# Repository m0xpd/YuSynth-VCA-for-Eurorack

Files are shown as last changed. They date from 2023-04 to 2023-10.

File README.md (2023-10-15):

# YuSynth-VCA-for-Eurorack

**A Eurorack Version of Yves Usson's 'Simple VCA'**



This repository contains design files for my Eurorack version of Yves Usson's 'Simple VCA' circuit:
http://yusynth.net/Modular/EN/VCA/index.html

which has been described in a stripboard implemementation on Eddy Bergman's Synth DIY site:
https://www.eddybergman.com/2020/04/synthesizer-build-part-29-vca-yusynth_25.html

**Circuit Description**

This Eurorack version is implemented on a single PCB, following closely Yves' original schematic.<p>(You can see my schematic as a graphic [here](https://github.com/m0xpd/YuSynth-VCA-for-Eurorack/blob/main/PCB/YuSynth%20Eurorack%20VCA%20Schematic.png) and the BoM is [here](https://github.com/m0xpd/YuSynth-VCA-for-Eurorack/blob/main/PCB/YuSynth%20VCA%20Eurorack%20v1%20BOM.txt) )

I have replaced the specified BC547 transistors with 2n3904s, as these are my everyday 'popcorn' NPNs. Yves does note this as a standard replacement 
and warns that the pinouts of the two transistors is revesed; 'CBE' becomes 'EBC'. 

My PCB is designed and silkscreened for 2n3904s, so if you want to swap back to the original BC547Cs, you'll have to place these 'in reverse' 
(i.e. with the flat face of the case aligned with the curve on the silkscreen).

I have also swapped the two IC packages (a TL072 and a LM741/TL071) for a single TL074 for two reasons:
Firstly, it is more efficient in terms of PCB area to do this.
Secondly, it is cheaper to do this; TL074s are more efficient than their smaller siblings (they only need one pair of power supply pins) but they're 
also very widely used so they are cheap, whereas TL072s and (particularly) TL071s are disproportionately expensive. Even more perversely, the old LM 
or uA741 (which was once the only op-amp in the shop) is now available only as a nostalgia piece, so it too sells for crazy money!

Having done this, I couldn't bear to have that extra op-amp stage doing nothing, so I gave both outputs independent active drive.

**Licensing the IP**

[][cc-by-nc-sa]

[cc-by-nc-sa]: http://creativecommons.org/licenses/by-nc-sa/4.0/
[cc-by-nc-sa-image]: https://licensebuttons.net/l/by-nc-sa/4.0/88x31.png
[cc-by-nc-sa-shield]: https://img.shields.io/badge/License-CC%20BY--NC--SA%204.0-lightgrey.svg  
  
Yves is clear on the position with copyright on his website:

"All circuits, schematics, printed circuit board, panel design and associated data published on (yusynth.net) can be used for private use only." 

and:

"The projects of (yusynth.net) may be build for personal, private usage or educative purpose. Commercial exploitation of the schematics, circuits, 
front panels and software shown on (yusynth.net), is not permitted without a formal agreement with (Yves Usson)".

Accordingly, **the copyright for this VCA circuit rests with Yves and no commercial exploitation is permitted**.

I have reflected this in the [License](LICENSE.txt) for the Eurorack version presented in this repository.

This work is licensed under a
[Creative Commons Attribution-NonCommercial-ShareAlike 4.0 International License.](https://creativecommons.org/licenses/by-nc-sa/4.0/deed.en)

**Hardware Design Files: PCB**

The PCB is described by .sch and .brd files and a BoM located in the [PCB folder](https://github.com/m0xpd/YuSynth-VCA-for-Eurorack/tree/main/PCB). 

**Hardware Design Files : Front Panel**

A front panel to complete the module is described by a simple Kicad project located in the [Front_Panel folder](https://github.com/m0xpd/YuSynth-VCA-for-Eurorack/tree/main/Front_Panel). 

**SetUp / Calibration**

Yves offers a [useful description of setup](http://yusynth.net/Modular/EN/VCA/index.html), which assumes the availability of an oscilloscope. 
I imagine the circuit could be setup adequately without a 'scope - but I've never tried to do it! Certainly an a.c. coupled build of this VCA
could be made to work adequately without access to a 'scope in the setup phase, but I think it would be tricky to setup a d.c. coupled version without access 
to appropriate test gear.

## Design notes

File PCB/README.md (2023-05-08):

[This folder](https://github.com/m0xpd/YuSynth-VCA-for-Eurorack/tree/main/PCB) contains design files for the Eurocard version of the YuSynth VCA printed circuit board developed in AutoCAD EAGLE.

These can be loaded into the (free) version of Eagle:
https://www.autodesk.co.uk/products/eagle/features
and are ready for the CAM processor to produce Gerber files ready to send to a PCB house. 

I have used JLCPCB (https://jlcpcb.com/) to produce the prototype seen in the pictures below (usual disclaimer). 
JLCPCB offer a file to set up the CAM processor to produce the Gerbers in the correct format - it is available (along with some guidelines) here:
https://support.jlcpcb.com/article/137-how-to-generate-gerber-and-drill-files-in-autodesk-eagle

I'm sure the other PCB houses offer an equivalent service - but I can't speak from first-hand experience.

The unpopulated board is seen here:

Unpopulated PCB

and the populated board is seen here (both from the 'front side', usually obscured by the front panel and from the back):

Populated PCB

**Bill of Materials**

The [BoM](https://github.com/m0xpd/YuSynth-VCA-for-Eurorack/blob/main/PCB/YuSynth%20VCA%20Eurorack%20v1%20BOM.txt) is presented in the rather verbose format produced by Eagle; some additional notes might be useful.

Firstly, Yves explains that two versions of the VCA can be constructed: an a.c. coupled version (for handling 'audio' signals) and a d.c. version 
(useful for controlling CV signals).

The a.c. coupled version is the standard build. It uses all the parts in the BoM. The three 100k control potentiometers should be logarithmic 
taper types in this application, 'A100K'. Linear taper potentiometers will work, but they will give the usual poor mapping between rotational angle 
and 'loudness'. Note that these potentiometers are named in my schematic with idents 'SIGLEVEL', 'GAIN', and 'CTLLEVEL' (Yves uses the idents 'P1', 'P2' 
and 'P3').

The d.c. coupled version is non-standard. To make the system d.c. coupled, capacitors C3 and C4 must be replaced by wire links. Also, the signal 
level monitor will not operate as intended and should be omitted (do not fit R24 & 25, C8 & 9 D1, LED1 and T4). In this case, the three control
potentiometers should be linear taper, 'B100K'.

I've made both versions.

Some components are mechanically critical in my design; the control potentiometers are 9mm vertical Alpha types such as [this](https://www.thonk.co.uk/shop/alpha-9mm-pots-vertical-t18/) and the jacks are [Thonkiconns](https://www.thonk.co.uk/shop/thonkiconn/).

Back in the day I used 3-way Molex KK connectors for powering modules and I still fit these as an alternative to the standard Eurorack power 
connector if space is available - you can omit the three way 'POWER' header if you don't plan to use it!

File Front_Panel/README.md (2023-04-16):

[This folder](https://github.com/m0xpd/YuSynth-VCA-for-Eurorack/tree/main/Front_Panel) contains design files for a front panel for the Eurorack version of the YuSynth VCA, developed in [Kicad](https://www.kicad.org/). 

The files constitute a simple [Kicad](https://www.kicad.org/) project - you may wish to modify my design to 'personalise' it.

The process of Gerber and drill file generation in Kicad seems to me to be a little more 'clunky' than in Eagle (because I'm used to Eagle's CAM
processor), but you'll find plenty of on-line tutorials explaining how to do it (such as [this one](https://www.lioncircuits.com/faq/pcb-fab/how-to-generate-the-gerber-files-using-kicad)).

My panel is seen here:

FrontPanelLowRes

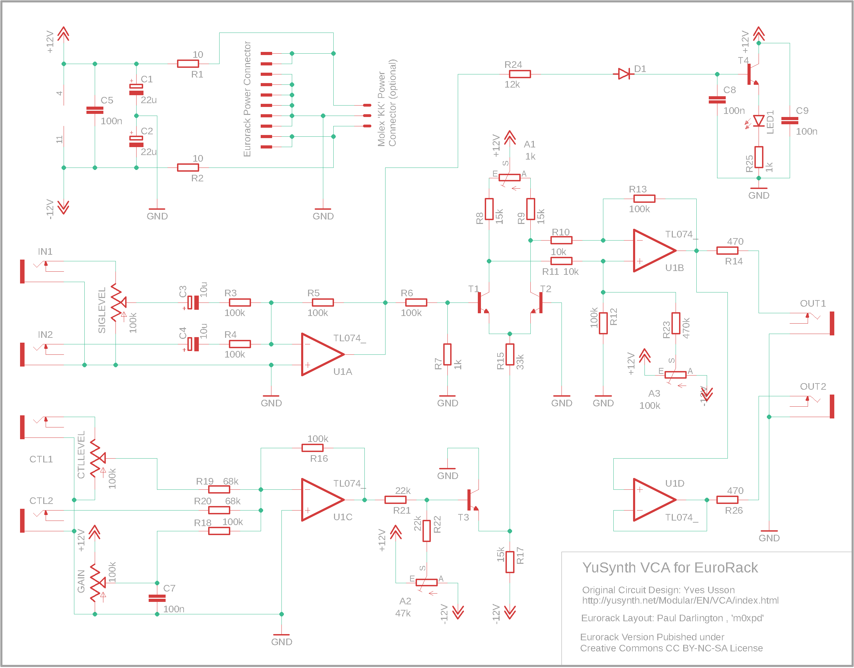
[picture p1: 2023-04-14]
PCB/YuSynth Eurorack VCA Schematic.png

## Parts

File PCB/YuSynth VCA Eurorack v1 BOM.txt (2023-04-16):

Partlist exported from /Users/pauldarlington/Documents/EAGLE/projects/YUSynth VCA/YuSynth VCA Eurorack v1.sch at 16/04/2023 07:21

Part           Value         Device           Package            Description                                       MF    MPN         OC_FARNELL OC_NEWARK POPULARITY SPICEPREFIX
A1             1k            TRIM_EU-B25P     B25P               POTENTIOMETER                                                                            7                     
A2             47k           TRIM_EU-B25P     B25P               POTENTIOMETER                                                                            7                     
A3             100k          TRIM_EU-B25P     B25P               POTENTIOMETER                                                                            7                     
C1             22u           CPOL-EUE2.5-5    E2,5-5             POLARIZED CAPACITOR, European symbol                                                     16         C          
C2             22u           CPOL-EUE2.5-5    E2,5-5             POLARIZED CAPACITOR, European symbol                                                     16         C          
C3             10u           CPOL-EUE2.5-5    E2,5-5             POLARIZED CAPACITOR, European symbol                                                     16         C          
C4             10u           CPOL-EUE2.5-5    E2,5-5             POLARIZED CAPACITOR, European symbol                                                     16         C          
C5             100n          C-EU050-025X075  C050-025X075       CAPACITOR, European symbol                                                               29         C          
C7             100n          C-EU050-025X075  C050-025X075       CAPACITOR, European symbol                                                               29         C          
C8             100n          C-EU050-025X075  C050-025X075       CAPACITOR, European symbol                                                               29         C          
C9             100n          C-EU050-025X075  C050-025X075       CAPACITOR, European symbol                                                               29         C          
CTL1           THONKICONNNEW THONKICONNNEW    WQP-PJ301M-12_JACK 3.5mm socket for Eurorack modular synths                                                                       
CTL2           THONKICONNNEW THONKICONNNEW    WQP-PJ301M-12_JACK 3.5mm socket for Eurorack modular synths                                                                       
CTLLEVEL       100k          9MM_SNAP-IN_POT_ 9MM_SNAP-IN_POT    9mm vertical snap-in pot, Alpha / Panasonic style                                                              
D1             1N4148DO35-7  1N4148DO35-7     DO35-7             DIODE                                                                                    58                    
EURORACK_POWER 2510-         2510-            PAK100/2500-10     3M (TM) Pak 100 4-Wall Header                     3M    2510-6002UB 9838244    46F4725   0                     
GAIN           100k          9MM_SNAP-IN_POT_ 9MM_SNAP-IN_POT    9mm vertical snap-in pot, Alpha / Panasonic style                                                              
IN1            THONKICONNNEW THONKICONNNEW    WQP-PJ301M-12_JACK 3.5mm socket for Eurorack modular synths                                                                       
IN2            THONKICONNNEW THONKICONNNEW    WQP-PJ301M-12_JACK 3.5mm socket for Eurorack modular synths                                                                       
LED1                         LED3MM           LED3MM             LED                                                                                      97                    
OUT1           THONKICONNNEW THONKICONNNEW    WQP-PJ301M-12_JACK 3.5mm socket for Eurorack modular synths                                                                       
OUT2           THONKICONNNEW THONKICONNNEW    WQP-PJ301M-12_JACK 3.5mm socket for Eurorack modular synths                                                                       
POWER          22-23-2031    22-23-2031       22-23-2031         .100" (2.54mm) Center Header - 3 Pin              MOLEX 22-23-2031  1462950    30C0862   35                    
R1             10            R-EU_0204/7      0204/7             RESISTOR, European symbol                                                                79         R          
R2             10            R-EU_0204/7      0204/7             RESISTOR, European symbol                                                                79         R          
R3             100k          R-EU_0204/7      0204/7             RESISTOR, European symbol                                                                79         R          
R4             100k          R-EU_0204/7      0204/7             RESISTOR, European symbol                                                                79         R          
R5             100k          R-EU_0204/7      0204/7             RESISTOR, European symbol                                                                79         R          
R6             100k          R-EU_0204/7      0204/7             RESISTOR, European symbol                                                                79         R          
R7             1k            R-EU_0204/7      0204/7             RESISTOR, European symbol                                                                79         R          
R8             15k           R-EU_0204/7      0204/7             RESISTOR, European symbol                                                                79         R          
R9             15k           R-EU_0204/7      0204/7             RESISTOR, European symbol                                                                79         R          
R10            10k           R-EU_0204/7      0204/7             RESISTOR, European symbol                                                                79         R          
R11            10k           R-EU_0204/7      0204/7             RESISTOR, European symbol                                                                79         R          
R12            100k          R-EU_0204/7      0204/7             RESISTOR, European symbol                                                                79         R          
R13            100k          R-EU_0204/7      0204/7             RESISTOR, European symbol                                                                79         R          
R14            470           R-EU_0204/7      0204/7             RESISTOR, European symbol                                                                79         R          
R15            33k           R-EU_0204/7      0204/7             RESISTOR, European symbol                                                                79         R          
R16            100k          R-EU_0204/7      0204/7             RESISTOR, European symbol                                                                79         R          
R17            15k           R-EU_0204/7      0204/7             RESISTOR, European symbol                                                                79         R          
R18            100k          R-EU_0204/7      0204/7             RESISTOR, European symbol                                                                79         R          
R19            68k           R-EU_0204/7      0204/7             RESISTOR, European symbol                                                                79         R          
R20            68k           R-EU_0204/7      0204/7             RESISTOR, European symbol                                                                79         R          
R21            22k           R-EU_0204/7      0204/7             RESISTOR, European symbol                                                                79         R          
R22            22k           R-EU_0204/7      0204/7             RESISTOR, European symbol                                                                79         R          
R23            470k          R-EU_0204/7      0204/7             RESISTOR, European symbol                                                                79         R          
R24            12k           R-EU_0204/7      0204/7             RESISTOR, European symbol                                                                79         R          
R25            1k            R-EU_0204/7      0204/7             RESISTOR, European symbol                                                                79         R          
R26            470           R-EU_0204/7      0204/7             RESISTOR, European symbol                                                                79         R          
SIGLEVEL       100k          9MM_SNAP-IN_POT_ 9MM_SNAP-IN_POT    9mm vertical snap-in pot, Alpha / Panasonic style                                                              
T1             2N3904        2N3904           TO92               NPN TRANSISTOR                                                                           27                    
T2             2N3904        2N3904           TO92               NPN TRANSISTOR                                                                           27                    
T3             2N3904        2N3904           TO92               NPN TRANSISTOR                                                                           27                    
T4             2N3904        2N3904           TO92               NPN TRANSISTOR                                                                           27                    
U1             TL074_        TL074_           DIL14              Generic Quad Op Amp

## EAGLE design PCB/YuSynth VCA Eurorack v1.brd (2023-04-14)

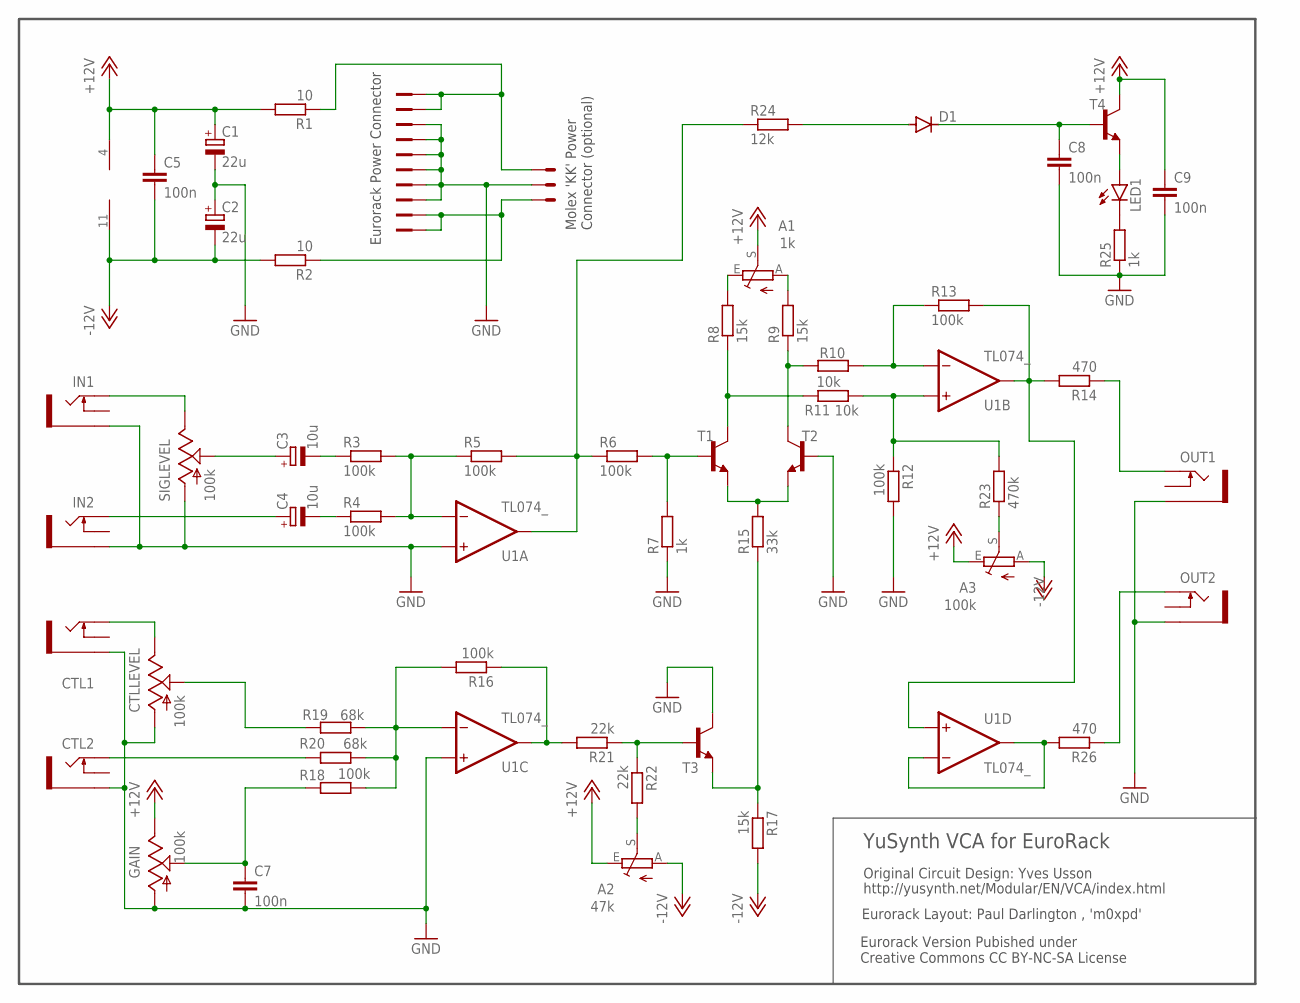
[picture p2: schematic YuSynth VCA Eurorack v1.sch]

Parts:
A1: 1k; B25P
A2: 47k; B25P
A3: 100k; B25P
C1, C2: 22u; E2,5-5
C3, C4: 10u; E2,5-5
C5, C7, C8, C9: 100n; C050-025X075
CTL1, CTL2: THONKICONNNEW; WQP-PJ301M-12_JACK
CTLLEVEL: 100k; 9MM_SNAP-IN_POT
D1: 1N4148DO35-7; DO35-7
EURORACK_POWER: 2510-; PAK100/2500-10
GAIN: 100k; 9MM_SNAP-IN_POT
IN1, IN2: THONKICONNNEW; WQP-PJ301M-12_JACK
LED1: LED3MM
OUT1, OUT2: THONKICONNNEW; WQP-PJ301M-12_JACK
POWER: 22-23-2031
R1, R2: 10; 0204/7
R3, R4, R5, R6, R12, R13, R16, R18: 100k; 0204/7
R7, R25: 1k; 0204/7
R8, R9, R17: 15k; 0204/7
R10, R11: 10k; 0204/7
R14, R26: 470; 0204/7
R15: 33k; 0204/7
R19, R20: 68k; 0204/7
R21, R22: 22k; 0204/7
R23: 470k; 0204/7
R24: 12k; 0204/7
SIGLEVEL: 100k; 9MM_SNAP-IN_POT
T1, T2, T3, T4: 2N3904; TO92
U1: TL074_; DIL14

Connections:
+12V: A1.S, A2.E, A3.E, C1.+, C5.1, C9.1, GAIN.3 (E), R1.2, T4.1 (C), U1.4 (V+)
-12V: A2.A, A3.A, C2.-, C5.2, R2.2, R17.2, U1.11 (V-)
GND: C1.-, C2.+, C7.2, C8.2, C9.2, CTL1.P$3_SLEEVE (SLEEVE), CTL2.P$3_SLEEVE (SLEEVE), CTLLEVEL.1 (A), EURORACK_POWER.3, EURORACK_POWER.4, EURORACK_POWER.5, EURORACK_POWER.6, EURORACK_POWER.7, EURORACK_POWER.8, GAIN.1 (A), IN1.P$3_SLEEVE (SLEEVE), IN2.P$3_SLEEVE (SLEEVE), OUT1.P$3_SLEEVE (SLEEVE), OUT2.P$3_SLEEVE (SLEEVE), POWER.2, R7.1, R12.2, R25.1, SIGLEVEL.1 (A), T2.2 (B), T3.1 (C), U1.3 (+IN), U1.10 (+IN)
unnamed: IN1.P$1_TIP (TIP), SIGLEVEL.3 (E)
unnamed: LED1.K (C), R25.2
unnamed: C3.+, SIGLEVEL.2 (S)
unnamed: C3.-, R3.1
unnamed: C4.+, IN2.P$1_TIP (TIP)
unnamed: C4.-, R4.1
unnamed: R3.2, R4.2, R5.1, U1.2 (-IN)
unnamed: R16.2, R18.1, R19.1, R20.1, U1.9 (-IN)
unnamed: R15.1, R17.1, T3.3 (E)
unnamed: CTL2.P$1_TIP (TIP), R20.2
unnamed: CTL1.P$1_TIP (TIP), CTLLEVEL.3 (E)
unnamed: R6.2, R7.2, T1.2 (B)
unnamed: R16.1, R21.2, U1.8 (OUT)
unnamed: R21.1, R22.1, T3.2 (B)
unnamed: A2.S, R22.2
unnamed: R8.1, R11.2, T1.1 (C)
unnamed: R9.1, R10.2, T2.1 (C)
unnamed: R15.2, T1.3 (E), T2.3 (E)
unnamed: A1.E, R8.2
unnamed: A1.A, R9.2
unnamed: A3.S, R23.1
unnamed: R10.1, R13.1, U1.6 (-IN)
unnamed: R11.1, R12.1, R23.2, U1.5 (+IN)
unnamed: R13.2, R14.2, U1.7 (OUT), U1.12 (+IN)
unnamed: D1.A, R24.2
unnamed: C8.1, D1.C, T4.2 (B)
unnamed: R26.2, U1.13 (-IN), U1.14 (OUT)
unnamed: OUT1.P$1_TIP (TIP), R14.1
unnamed: LED1.A, T4.3 (E)
unnamed: R5.2, R6.1, R24.1, U1.1 (OUT)
unnamed: OUT2.P$1_TIP (TIP), R26.1
unnamed: CTLLEVEL.2 (S), R19.2
unnamed: C7.1, GAIN.2 (S), R18.2
unnamed: EURORACK_POWER.9, EURORACK_POWER.10, POWER.1, R1.1
unnamed: EURORACK_POWER.1, EURORACK_POWER.2, POWER.3, R2.1

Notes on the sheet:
YuSynth VCA for EuroRack
Original Circuit Design: Yves Usson
Eurorack Layout: Paul Darlington , 'm0xpd'
Eurorack Version Pubished under Creative Commons CC BY-NC-SA License
Eurorack Power Connector
Molex 'KK' Power Connector (optional)
http://yusynth.net/Modular/EN/VCA/index.html

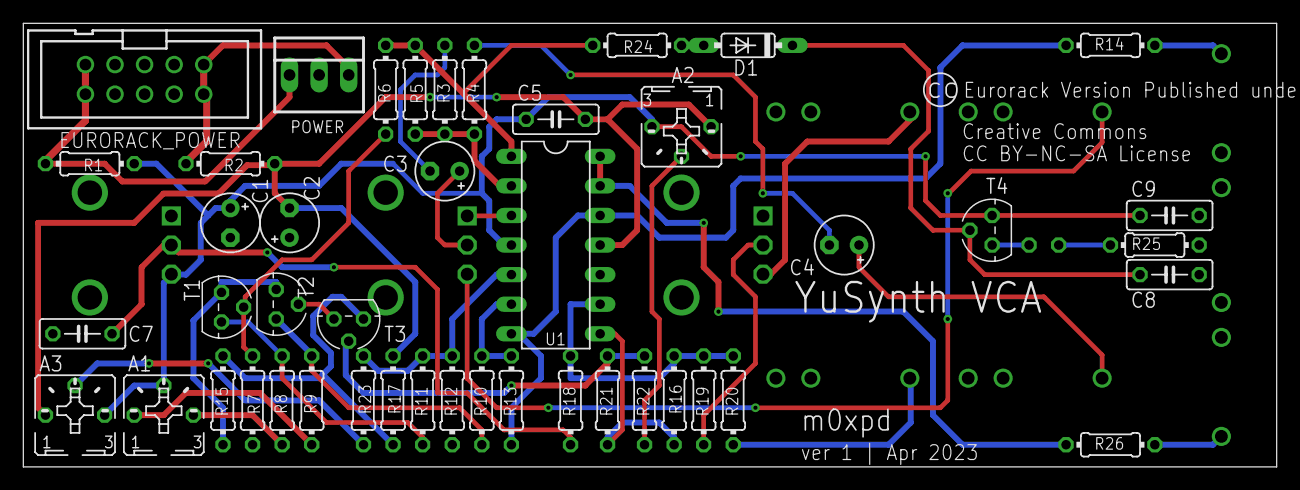
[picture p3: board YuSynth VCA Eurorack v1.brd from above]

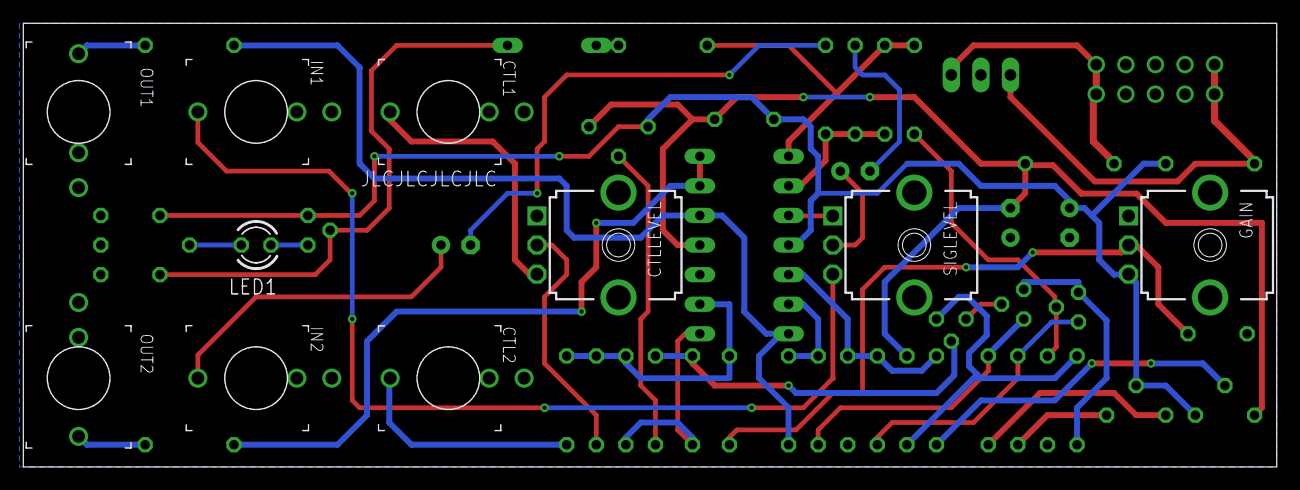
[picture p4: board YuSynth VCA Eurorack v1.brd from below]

Board: 2 copper layers, 107.6 x 38.1 mm, 55 parts (10 on the bottom side), 38 nets.

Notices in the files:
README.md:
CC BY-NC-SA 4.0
